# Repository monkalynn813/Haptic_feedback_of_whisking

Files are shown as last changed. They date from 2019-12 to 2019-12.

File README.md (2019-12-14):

# A Haptic Feedback Device to simulate whisking of A Robotic Rat

#### _Jingyan Ling_
**October ~ December 2019**

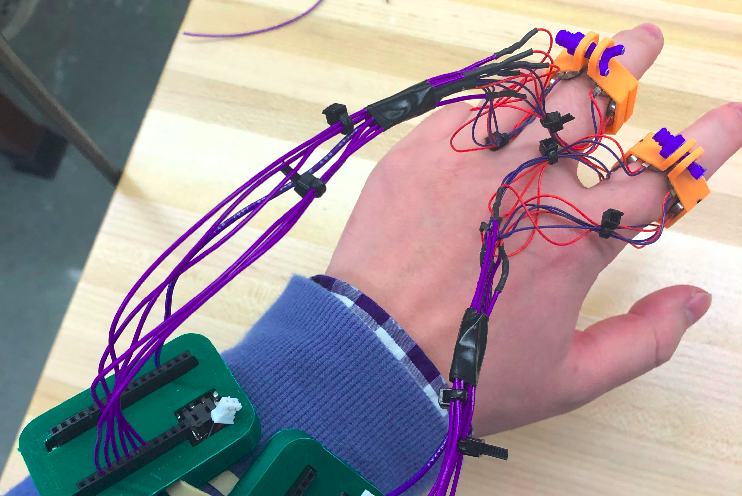
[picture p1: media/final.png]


The objective of this project is to develop a haptic feedback device to simulate the active whisking of a robotic rat. Previous works have demonstrated that rats can sense the environment from the bending of their whiskers. This project tries to explore this phenomenon by delivering such a sense of bending to humans haptically. The device includes six micro vibration motors in a group to represent the magnitude and direction of a signal. We use the Wi-Fi module of multiple micro-controllers to have a portable and accessible device.

## Method

#### System Pipeline

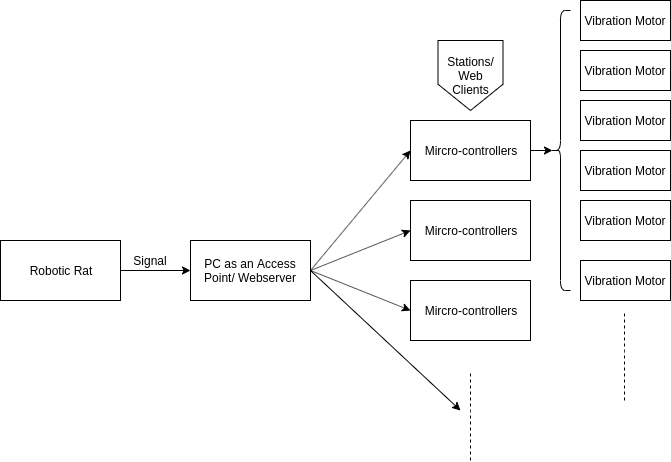
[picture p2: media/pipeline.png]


We use vibration motors to represent signals from the robotic rat. The computer receives the signal through the USB port and serves as an Access Point to broadcast filtered signals. Several micro-controller connect to the AP, serves as stations, and listen to incoming signals. Each micro-controller is assigned to proceed with one whisker data and uses output compare pins to control motors based on the direction and magnitude of such data. The stream of signals from the robotic rat was tested at 200Hz. Each vibration motor updates its frequency at 1Hz.

#### Algorithm & Research Settings

- Direction of the signal
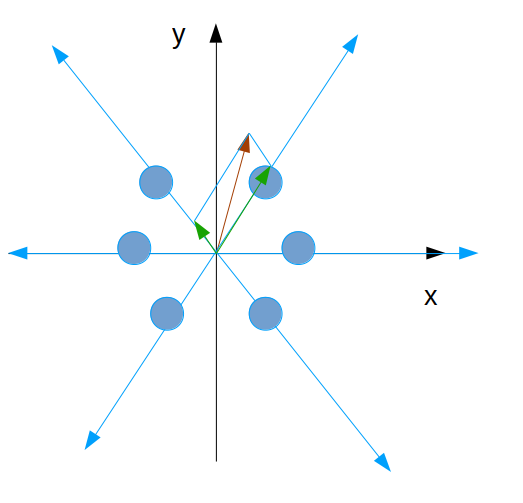
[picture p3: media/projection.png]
  - 
  - Each signal in x-y plane is projected on to 3 axes:
    - Basis 1: (1 , 0)
    - Basis 2: (cos 60, sin 60)
    - Basis 3: (-cos 60, sin 60)
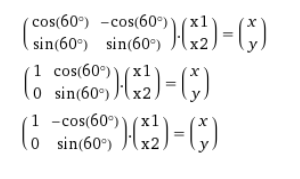
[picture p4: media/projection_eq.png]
    - 
  - Use two motors to provides contrast and enhance the actual feeling from human Magnitude of the signal.
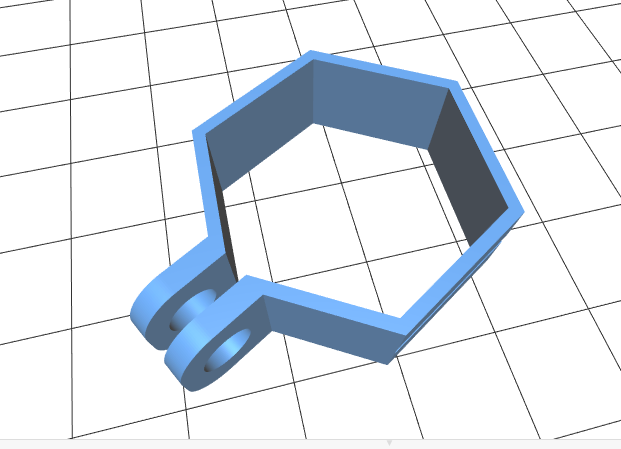
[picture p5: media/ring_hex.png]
  - 

#### Micro-controller
- The micro-controllers serves as web clients that listen to the data streaming at the webserver. 
- The micro-controllers listen to the data at 1Hz and compute duty cycles of PWM on each output compare pin.
- Even each micro-controller listens to data of all whiskers, it only computes and generates PWM waveforms for a specific whisker. 
- Each micro-controller controls one 'ring', which has six vibration motors.

## Result & Implementation Instruction

#### Test Environment

- Hardware:
  - [Adafruit Feather M0 WiFi - ATSAMD21 + ATWINC1500](https://www.adafruit.com/product/3010)
  - [Micro Vibration Motors](https://www.amazon.com/tatoko-Vibration-Button-Type-Vibrating-Appliances/dp/B07L5SY539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)
  - 3D printed Mechanical Designs:
    - [Hex Ring](me_designs/ring-hex-2.stl)
    - [MCU Case Lid](me_designs/haptic_lid.stl)
    - [MCU Case Base](me_designs/haptic_base.stl)
    - [Hex Ring - Screw](me_designs/haptic_screw.stl)
    - [Hex Ring - Nut](me_designs/haptic_nut.stl)
- Software:
  - [Arduino IDE](https://www.arduino.cc/en/main/software)
  - Python 3.7

#### Result & Implementation 

`0. Hardware Connection`

 - Connect micro vibration motors as follows
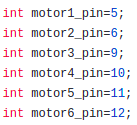
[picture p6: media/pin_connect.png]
 - 
 - See [here](https://learn.adafruit.com/adafruit-feather-m0-wifi-atwinc1500/pinouts) for pin out of the micro-controller,

`1.  AP Connection`

  - Turn on the WiFi HotSpot of the PC by following this [instruction](https://help.ubuntu.com/stable/ubuntu-help/net-wireless-adhoc.html.en) or the documentation of your PC distribution.
  - Type in your username and password in [arduino_secrets.h](w_feather/arduino_code/MCU_as_webclient/arduino_secrets.h).
  - 
  - Look for the IP address of the AP by command line `ifconfig -a` or the documentation of your PC distribution.
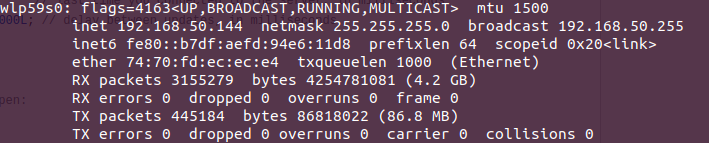
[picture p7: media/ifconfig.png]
  - 
  - Type in the IP address at `line 22` of [MCU_as_webclient.ino](w_feather/arduino_code/MCU_as_webclient/MCU_as_webclient.ino)
  - 

`2. Whisker for each MCU`

- Modify the global variable `WHISKER_INDEX` in [projection.h](w_feather/arduino_code/MCU_as_webclient/projection.h).
- Specify the maximum magnitude of the incoming signals (default: 100.0)
- Specify the lowest effective vibration duty cycle (default: 45)
- 
- Load the code to micro-controllers.

`3 Webserver and Data Stream`
- Run [create_webserver.py](w_feather/create_webserver.py) and micro-controllers should connect to the server automatically.
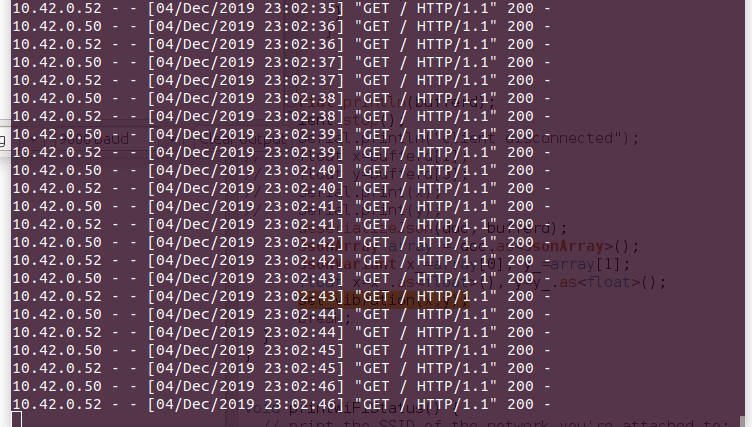
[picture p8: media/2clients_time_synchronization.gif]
- 
- Stream the data by running [data_stream.py](w_feather/data_stream.py) after specify your data in the file.
- If one of the micro-controller is connected to the PC through a USB port. The following message would show up in Arduino message window.
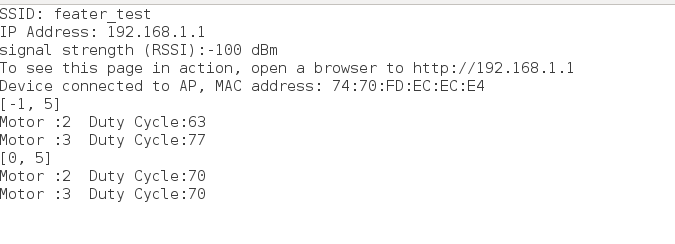
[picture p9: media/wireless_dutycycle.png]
- 

`4. Result`
- You should be able to see the result from windows
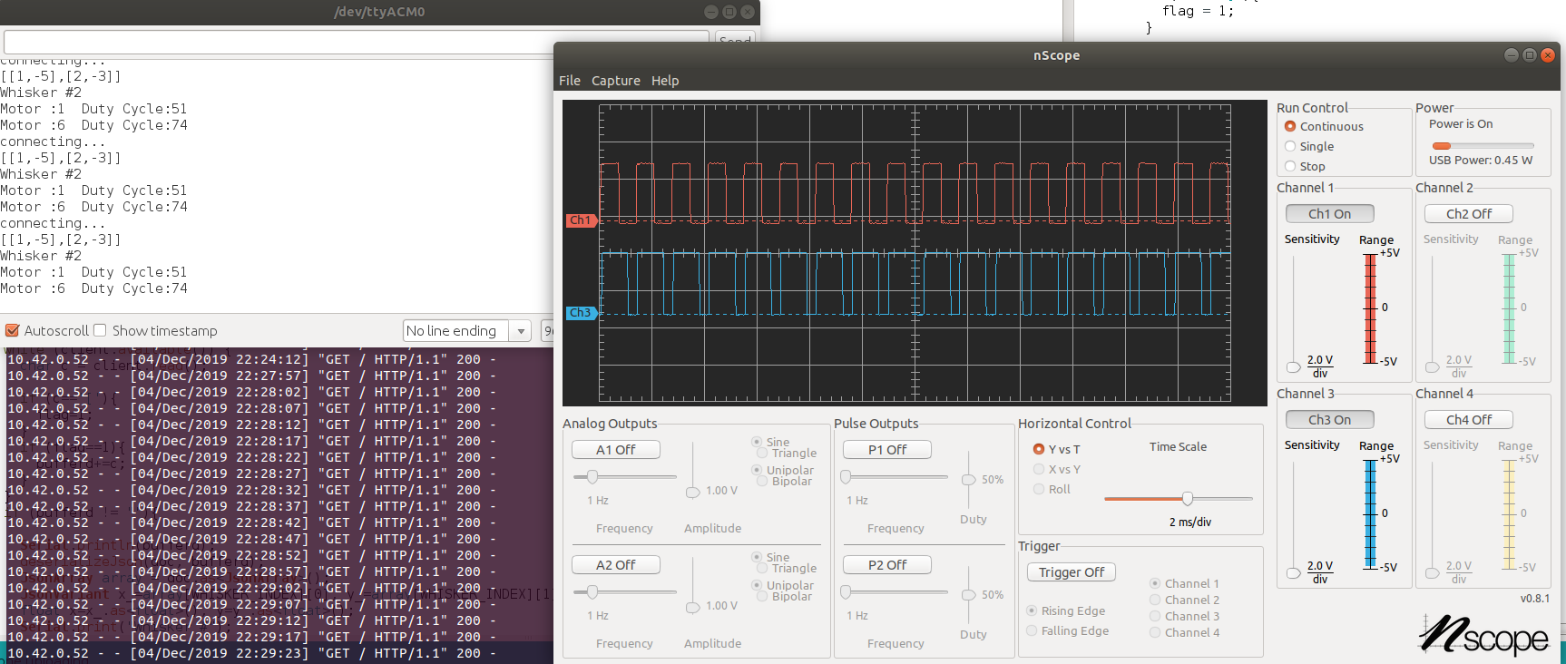
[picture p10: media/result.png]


- Feel the message from a rat on your fingers!

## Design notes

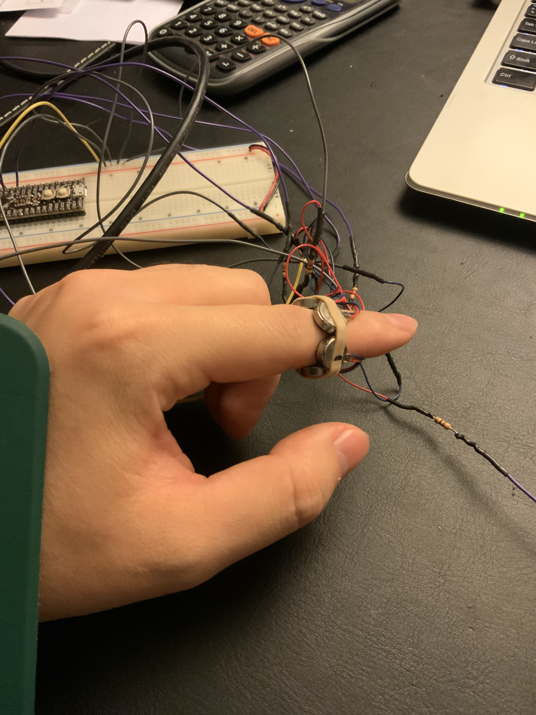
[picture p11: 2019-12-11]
media/mech_design_ver2.jpg

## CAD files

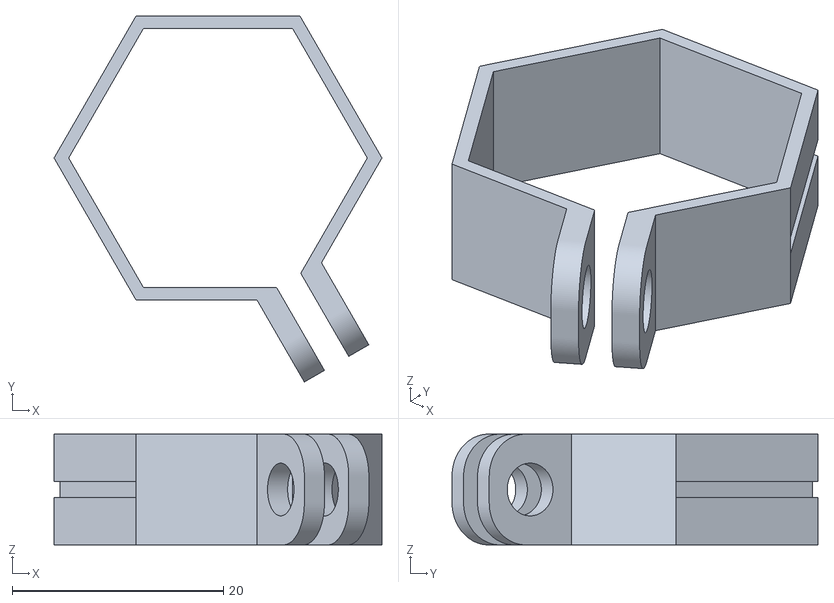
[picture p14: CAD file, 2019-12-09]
me_designs/ring-hex-2.stl
31.1 x 34.7 x 10.5

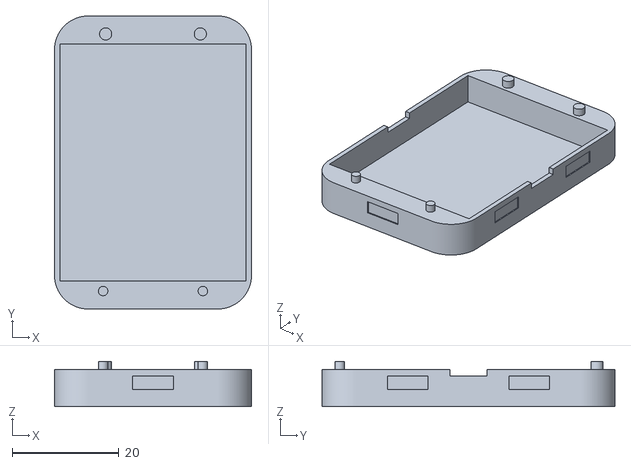
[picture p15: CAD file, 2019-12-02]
me_designs/haptic_base.stl
37.0 x 55.0 x 8.50

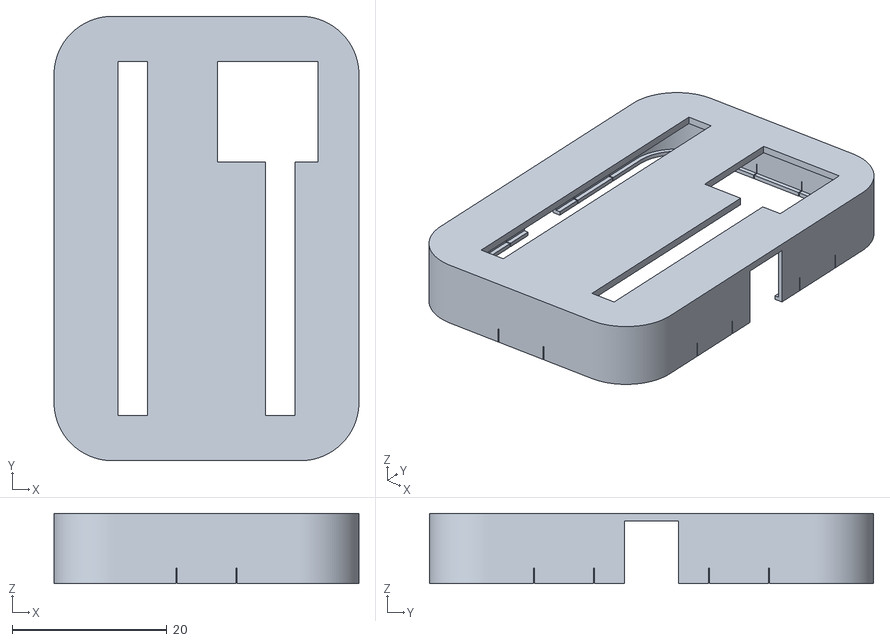
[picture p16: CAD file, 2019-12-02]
me_designs/haptic_lid.stl
39.4 x 57.4 x 9.05

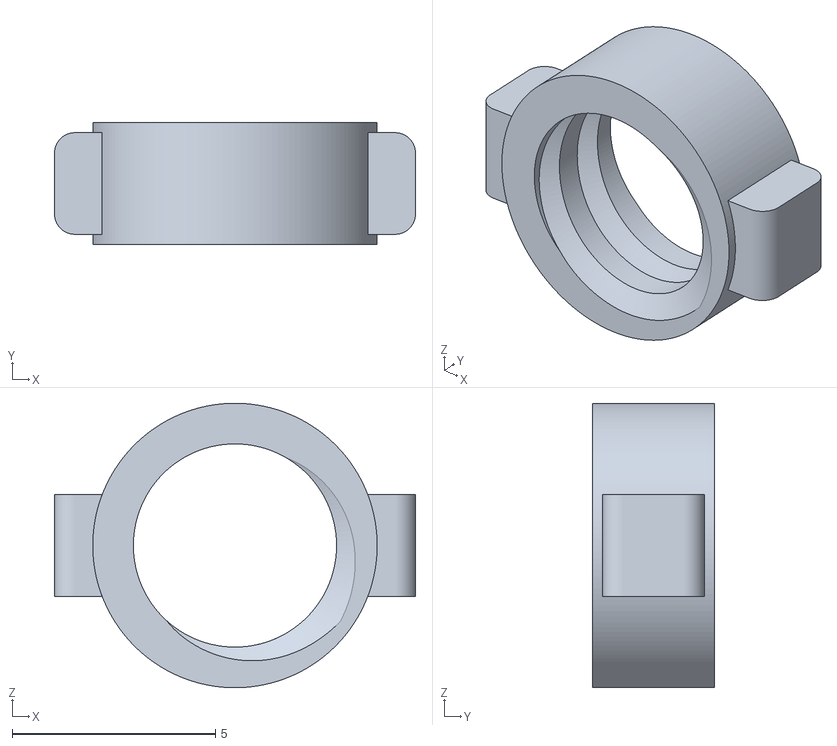
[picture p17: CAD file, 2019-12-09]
me_designs/haptic_nut.stl
8.88 x 3.00 x 7.00

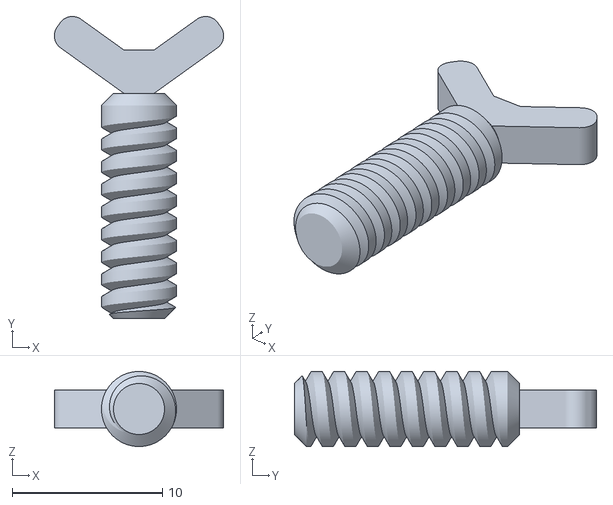
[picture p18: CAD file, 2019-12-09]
me_designs/haptic_screw.stl
11.3 x 20.1 x 5.00

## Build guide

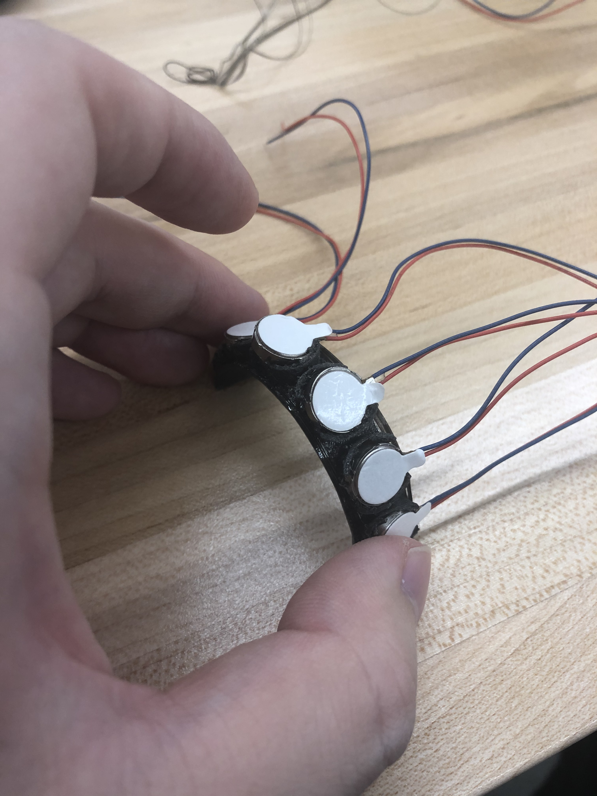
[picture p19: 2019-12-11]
media/3d_print_soft2.jpg

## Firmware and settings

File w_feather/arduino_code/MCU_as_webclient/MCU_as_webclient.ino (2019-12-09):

#include <SPI.h>
#include <WiFi101.h>
#include <ArduinoJson.h>
#include "projection.h"
#include "arduino_secrets.h" 



///////please enter your sensitive data in the Secret tab/arduino_secrets.h
char ssid[] = SECRET_SSID;        // your network SSID (name)
char pass[] = SECRET_PASS;    // your network password (use for WPA, or use as key for WEP)
int keyIndex = 0;            // your network key Index number (needed only for WEP)

int status = WL_IDLE_STATUS;

// Initialize the WiFi client library
WiFiClient client;

// server address:
//char server[] = "www.arduino.cc";
IPAddress server(10,42,0,1);

unsigned long lastConnectionTime = 0;            // last time you connected to the server, in milliseconds
const unsigned long postingInterval = 1L * 1000L; // delay between updates, in milliseconds

void setup() {
  feather_setup();
  //Initialize serial and wait for port to open:
  Serial.begin(9600);
//  while (!Serial) {
//    ; // wait for serial port to connect. Needed for native USB port only
//  }

  // check for the presence of the shield:
  if (WiFi.status() == WL_NO_SHIELD) {
    Serial.println("WiFi shield not present");
    // don't continue:
    while (true);
  }

  // attempt to connect to WiFi network:
  while ( status != WL_CONNECTED) {
    Serial.print("Attempting to connect to SSID: ");
    Serial.println(ssid);
    // Connect to WPA/WPA2 network. Change this line if using open or WEP network:
    status = WiFi.begin(ssid, pass);

    // wait 10 seconds for connection:
    delay(10000);
  }
  // you're connected now, so print out the status:
  printWiFiStatus();
}

void loop() {
  StaticJsonDocument<100> doc;
  String bufferd= "";
  int flag=0;

  // if there's incoming data from the net connection.
  // send it out the serial port.  This is for debugging
  // purposes only:
  while (client.available()) {
    char c = client.read();

    if (c=='['){
      flag=1;
    }
    if (flag==1){
      bufferd+=c;
    }
  }
  if (bufferd != ""){
  
    Serial.println(bufferd);
    deserializeJson(doc, bufferd);
    JsonArray array = doc.as<JsonArray>();
    JsonVariant x_=array[WHISKER_INDEX][0], y_=array[WHISKER_INDEX][1];
    float x=x_.as<float>(), y=y_.as<float>();
    Serial.print("Whisker #");
    Serial.println(WHISKER_INDEX+1);
    set_vibration(x,y);
  }
  // if ten seconds have passed since your last connection,
  // then connect again and send data:
  if (millis() - lastConnectionTime > postingInterval) {
    httpRequest();
  }

}

// this method makes a HTTP connection to the server:
void httpRequest() {
  // close any connection before send a new request.
  // This will free the socket on the WiFi shield
  client.stop();

  // if there's a successful connection:
  if (client.connect(server, 8000)) {
    Serial.println("connecting...");
    // send the HTTP PUT request:
    client.println("GET / HTTP/1.1");
    client.println("Host: 10.42.0.1");
    client.println("User-Agent: ArduinoWiFi/1.1");
    client.println("Connection: close");
    client.println();

    // note the time that the connection was made:
    lastConnectionTime = millis();
  } else {
    // if you couldn't make a connection:
    Serial.println("connection failed");
  }
}


void printWiFiStatus() {
  // print the SSID of the network you're attached to:
  Serial.print("SSID: ");
  Serial.println(WiFi.SSID());

  // print your WiFi shield's IP address:
  IPAddress ip = WiFi.localIP();
  Serial.print("IP Address: ");
  Serial.println(ip);

  // print the received signal strength:
  long rssi = WiFi.RSSI();
  Serial.print("signal strength (RSSI):");
  Serial.print(rssi);
  Serial.println(" dBm");
}

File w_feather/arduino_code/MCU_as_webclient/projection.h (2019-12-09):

#ifndef PROJECTION_H
#define PROJECTION_H


#define WHISKER_INDEX 0
#define MAX_BEND 100.0
//#define MAX_BEND 7.07
#define LOWEST_EFFECT_VIB 45


int motor1_pin=5;
int motor2_pin=6;
int motor3_pin=9;
int motor4_pin=10;
int motor5_pin=11;
int motor6_pin=12;


void feather_setup(){
  WiFi.setPins(8,7,4,2);
  pinMode(motor1_pin, OUTPUT);
  pinMode(motor2_pin, OUTPUT);
  pinMode(motor3_pin, OUTPUT);
  pinMode(motor4_pin, OUTPUT);
  pinMode(motor5_pin, OUTPUT);
  pinMode(motor6_pin, OUTPUT);
  analogWrite(motor1_pin,0);
  analogWrite(motor2_pin,0);
  analogWrite(motor3_pin,0);
  analogWrite(motor4_pin,0);
  analogWrite(motor5_pin,0);
  analogWrite(motor6_pin,0);
}



void set_pwm(int motor_pin, int dc){
  
  int pin, cycle= dc/100.0*255;
  if (motor_pin==1){
    pin=5;
  }
  else if(motor_pin==2){
    pin=6;
  }
  else if(motor_pin==3){
    pin=9;
  }
  else if(motor_pin==4){
    pin=10;
  }
  else if(motor_pin==5){
    pin=11;
  }
  else if(motor_pin==6){
    pin=12;
  }
  
  analogWrite(pin,cycle);
}


void set_vibration(float x, float y){
    double alpha=atan2(y,x);
    int act_1, act_2; //activate which motor
    float x1, x2; 
    int dc_1,dc_2; //desired duty cycle

    if(((alpha> 60.0*M_PI /180) && (alpha < 120.0*M_PI/180)) || ((alpha > -120.0*M_PI /180) && (alpha < -60*M_PI/180))){
        //x1 refer to axis 2, x2 refer to axis 3
        x2 = y / sqrt(3.0) - x;
        x1= 2* x +x2;
       
        if(x1>=0){
            act_1=2;
        }
        else{
            act_1=5;
        }
        if(x2>=0){
            act_2=3;
        }
        else{
            act_2=6;
        }
          

    }
    else if((alpha>=0 && alpha<= 60.0 *M_PI/180) || (alpha>= -M_PI && alpha <= -120.0*M_PI/180)){
        //x1 refer to axis 2, x2 refer to axis 3

        x2 = 2.0*y / sqrt(3.0);
        x1= x - x2* 0.5;
       
        if(x1>=0){
            act_1=1;
        }
        else{
            act_1=4;
        }
        if(x2>=0){
            act_2=2;
        }
        else{
            act_2=5;
        }
        

    }
    else{
        //x1 refer to axis 2, x2 refer to axis 3

        x2 = 2.0*y / sqrt(3.0);
        x1= x + x2* 0.5;
       
        if(x1>=0){
            act_1=1;
        }
        else{
            act_1=4;
        }
        if(x2>=0){
            act_2=3;
        }
        else{
            act_2=6;
        }

    }
    analogWrite(motor1_pin,0);
    analogWrite(motor2_pin,0);
    analogWrite(motor3_pin,0);
    analogWrite(motor4_pin,0);
    analogWrite(motor5_pin,0);
    analogWrite(motor6_pin,0);

    
    dc_1=((100-LOWEST_EFFECT_VIB)/MAX_BEND)*fabs(x1)+LOWEST_EFFECT_VIB;
    dc_2=((100-LOWEST_EFFECT_VIB)/MAX_BEND)*fabs(x2)+LOWEST_EFFECT_VIB;
    if (dc_1==LOWEST_EFFECT_VIB){
      dc_1=0;
    }
    if (dc_2==LOWEST_EFFECT_VIB){
      dc_2=0;
    }
    set_pwm(act_1,dc_1);
    set_pwm(act_2,dc_2);
    

    Serial.print("Motor :");
    Serial.print(act_1);
    Serial.print("  Duty Cycle:");
    Serial.println(dc_1);
    Serial.print("Motor :");
    Serial.print(act_2);
    Serial.print("  Duty Cycle:");
    Serial.println(dc_2);

}



#endif

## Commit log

2019-12-02 update designs
    [haptic_base.stl, haptic_lid.stl]
2019-12-09 multi-mcu success
    [haptic_nut.stl, haptic_screw.stl, ring-hex-2.stl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]
2019-12-11 code cleanup, start doc
    [augmented_data.csv, ring.stl]
